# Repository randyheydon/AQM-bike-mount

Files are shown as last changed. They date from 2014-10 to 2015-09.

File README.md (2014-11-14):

# Air Quality Monitor bicycle mount

These parts are designed to help mount an Air Quality Monitor to your bicycle.  They are specifically designed for the Dylos DC1700 being used by Environment Hamilton for their [Bicycle Air Monitoring project](http://www.environmenthamilton.org/view/page/BAM).

Mounting to a bicycle requires at least two of the given parts (a clip and a mount), plus some collection of fasteners.  The clip is designed to snap around the monitor, and the mounts allow it to be attached to different areas on the bike.

## Fasteners

If using the clip with the handlebar mount, you will need:

* 1 M5 bolt, socket head, 12mm-14mm long
* 1 M5 hex nut
* 1 M3 bolt, any head (thumbscrew preferred), 30mm or longer
* 1 M3 hex nut (or wing nut combined with hex head bolt)

If using the clip with the bottle hole mount (designed to attach to the braze-ons that are typically used to hole water bottle cages) you will need:

* 1 M5 bolt, socket head, 30mm-65mm long
* 1 M5 hex nut
* 2 M5 bolts of proper length for your braze-ons (probably included with your bike)

# License

<br /><span xmlns:dct="http://purl.org/dc/terms/" property="dct:title">AQM bike mount</span> by <a xmlns:cc="http://creativecommons.org/ns#" href="https://github.com/Tempel/AQM-bike-mount" property="cc:attributionName" rel="cc:attributionURL">Randy Heydon</a> is licensed under a <a rel="license" href="http://creativecommons.org/licenses/by-sa/4.0/">Creative Commons Attribution-ShareAlike 4.0 International License</a>.

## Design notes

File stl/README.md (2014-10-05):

**Do not edit these files**

These STL files are generated from the FCSTD files in the folder above this.
If you wish to modify anything in them, you should do so from the FCSTD file in
FreeCAD, and re-export the STL.  These files are included in this repository
solely to make it easier for others to use them without access to FreeCAD.

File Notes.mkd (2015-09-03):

# Build notes

## Prototype 2

Again printed by Nick, with the same parameters.  Left with Environment
Hamilton to test, and eventually had a chance to try it myself.

* Clip is too flexible, because I messed up my math: deflection should be
  inversely proportional to the *cube* of the thickness, not linearly.  Clip
  manages to hold the AQM fairly well, and adding an elastic made it much
  better, but it could be stiffer and a little tighter around the AQM.
* Some volunteers left the velcro straps on the AQM while clipping it in, using
  the straps as emergency backups in case the clip let go.  I tried this, and
  it made the clip not fit the AQM correctly as it wasn't designed for the
  extra space.  Still, this may be a good thing to allow for.
* Handlebar mount had a serious failure when trying to attach to too-small
  handlebars.  Cranking the wing nut made it stay on, but it forced the screw
  to dig into the sides of its hole, preventing it from loosening.  Had to pry
  it apart with a claw hammer, which snapped the plastic through the hexagonal
  recess.  It's still maybe usable, but I don't think anyone tried.  Probably
  needs a serious redesign.
* The bottle hole mount is too weak laterally.  It is only supported against
  side-to-side motion at the two braze-ons, giving a narrow moment arm.  This
  results in it splitting the layers next to the bolt holes and swaying very
  significantly during use.  It's also a little longer than it needs to be.

Improvements for the next round:

* Increase clip wall thickness from 2.5 mm to 3 mm.  Based on the first
  prototype's deflection measurements, this gives a total deflection of 24mm.
  Combined with the ends having been opened by 20 mm, this should give total
  opening of 44 mm, close to the 40 mm I previously targeted.

## Prototype 1

Kindly printed by Nick, with 30% fill in a crosshatch pattern.  Thoughts:

* Clip is definitely not flexible enough.  Can open by approximately 10 mm
  across both sides of the clip, but needs to open by ~40 mm to get in the
  monitor.  Might need just 20 mm, but it's hard to tell without having the AQM
  on hand.
* The handlebar mount doesn't really work for my bike.  The double-bent shape
  of the handlebars doesn't leave enough width for the clip.
* On top of that, the handlebar mount works great for 25 mm diameter bars (ISO
  standard), but does not grip on anything smaller, and does not fit on anything
  larger.
* The bottle hole mount indented base is way too steep; on my bike, it nestles
  right in the bottom radius.  That's embarrassing, since I should have checked
  that better before I completed it.
* Fasteners are a problem in that my local Canadian Tire only carries one of
  the several that I need.  Their M5 bolts only go as long as 30 mm, not the 60
  I need, and they don't have any M3 bolts, only going as small as M4.
* One more: the recess for the nut in the handlebar clip is too shallow to hold
  the nut permanently, making it susceptible to being lost.

Things I can do to improve these:

* First, thin the clip walls from 4 mm to 2.5; the area moment should decrease
  linearly, and deflection should be inversely proportional to that, bringing
  deflection to 16 mm.  For the rest, I'll open up the ends of the clip by
  another 20 mm (10 mm per side), giving a total of 36 mm, which is close
  enough, right?
* I'll lengthen it by about 3mm for now.  I'm not too concerned with my own
  bike, since I want to use the bottle hole mount anyways, but some extra space
  might be useful in the future.
* Not much can be done on the bar diameter without a serious clamp redesign.
  I think this will be good enough for standard handlebars for now, and I'll
  wait for feedback on where else people want to clamp it before I make another
  mount design.  But to make it slightly more flexible, I'll thin the clamp
  walls from 3.5mm to 2.5mm.
* You know what, that angled base idea was dumb anyways.  I'll change it to a
  flat base so it can be used with washers if available.  And I'll make the
  whole thing narrower since the width won't be supporting anything.
* I'll order a bunch of fasteners from McMaster-Carr instead of getting them
  from Canadian Tire.  More expensive, but I don't need many.  Also, I'll make
  the nut hole in the bottle hole mount deeper to support bolts down to 30mm.
* I'll make the ends of the handlebar clamp thicker so as to fully encase an M3
  nut.  This will require a slightly longer bolt; the README will be updated
  accordingly.

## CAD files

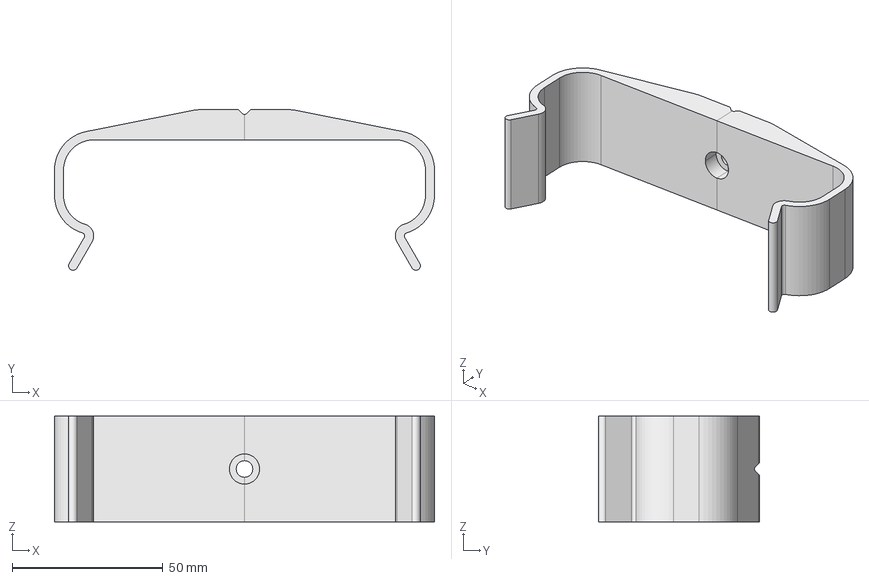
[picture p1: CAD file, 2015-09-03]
clip.fcstd
126.0 x 53.2 x 35.0 mm

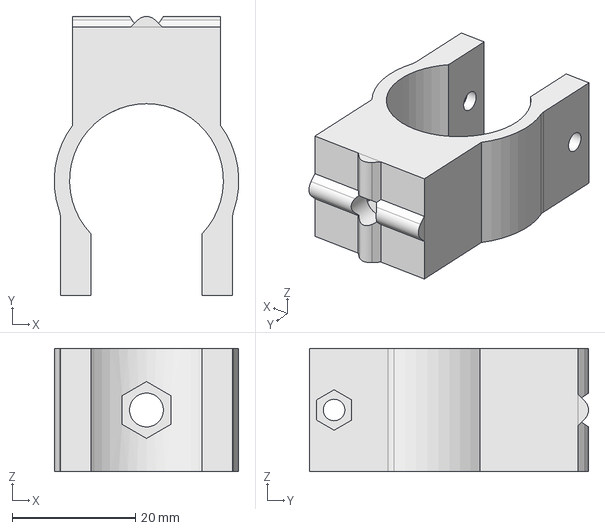
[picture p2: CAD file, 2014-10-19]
handlebar mount.fcstd
30.0 x 45.3 x 20.0 mm

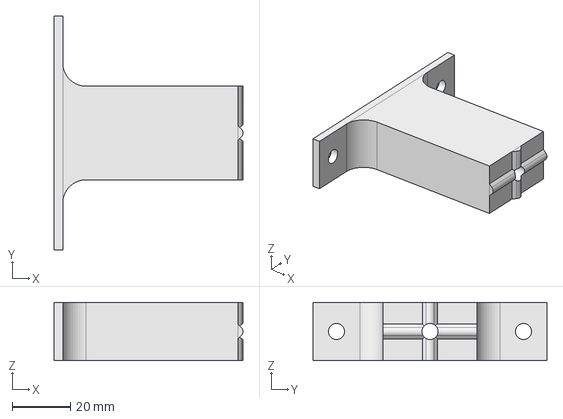
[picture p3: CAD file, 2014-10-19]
bottle hole mount.fcstd
64.7 x 80.0 x 20.0 mm

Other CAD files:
stl/bottle hole mount.stl
stl/clip.stl
stl/handlebar mount.stl

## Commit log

2014-10-04 A nice clip design for the air quality monitor.
    [clip.fcstd]
2014-10-04 Mirrored base clip for the air quality monitor to create final model.
    [clip.fcstd]
2014-10-05 Complete mount for applying to the holes that hold on a bottle cage.
    [bottle hole mount.fcstd]
2014-10-05 Slight increase to the depth of the nut hole to allow looser size selection.
    [bottle hole mount.fcstd]
2014-10-05 Complete mount for applying to handlebars. Requires M3 bolt and nut.
    [handlebar mount.fcstd]
2014-10-05 Adding exported STL files for printing.
    I know, generated files shouldn't be committed to a repository. But I'm trying
    to ease others' access, as well as allowing GitHub to display them in-browser.
    [bottle hole mount.stl, clip.stl, handlebar mount.stl]
2014-10-05 Added Readme describing fasteners needed to assemble everything.
2014-10-19 Reviewed first prints, made notes and edits.
    Identified a number of problems with the initial design, discussed in
    Notes.mkd. Modified all models accordingly (it was a lot of work as they
    frequently broke when modifying the feature tree) and re-exported STLs.
    [bottle hole mount.fcstd, bottle hole mount.stl, clip.fcstd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]
2014-11-14 Add wing nut option (as I have for real) to README.
2014-11-14 Added some initial observations on prototype 2.
    Left prototype 2 with Environment Hamilton; they will hopefully provide some
    more feedback that can be added.
2015-08-09 Further observations after my own use of prototype2.
    I finally got to do another round with the AQM, testing out the clips in the
    process. I also managed to get some verbal feedback from other people who've
    tried it. This was all added into the notes.
2015-09-03 Improvement to clip by thickening wall from 2.5 to 3 mm.
    Will stiffen everything slightly to get what should be the ideal amount of
    deflection.
    [clip.fcstd, clip.stl]
